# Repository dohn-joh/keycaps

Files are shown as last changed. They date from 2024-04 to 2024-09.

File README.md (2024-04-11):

This repo contains all of the keycaps that I've designed.
I've included parameterized fusion360 files that anyone is free to edit.

# Lever Keycaps
Demo video: https://vimeo.com/897496865

## Switch compatibility
Choc: tested and compatible with choc v1.
MX: currently only tested and working with Outemu Lemon/Lime switches. If your MX switch has a different stem mount, these may not be compatible!
If you use a different switch, you will need to reference the datasheet for your switch, note the pre-travel distance and change the "heel" parameter accordingly.
    
## Notes
- These keycaps will make your switches feel lighter due to leverage. A heavier switch may actually feel better than a lighter one.
- They will alter the actuation distance. You can adjust the parameters to increase or decrease the actuation distance.
- I tried my best to parameterize things, but my sketches are not perfect. Double check the sketches and bodies after changing parameters.

## Hardware and tools required 
Hinge: dressmaker pin with 0.7mm shaft diameter. A box of 350 goes for $4-5 in a brick and mortar store. The exact model used was dritz #22, size 20 (1 ¼") nickel plated steel. it's a little more expensive on amazon. https://www.amazon.com/dp/B003W0TIH6/
You can use other materials for the hinge and change the hole parameters as needed.
Flush cutters: to trim the excess hinge
Optional: tweezer pliers for grabbing and inserting the hinge

## Slicer settings (PLA)
3mf file contains the slicer settings I used in orcaslicer.
The supports are important or the overhangs will sag.

## Assembly
Simply print, remove mouse ears, line up the holes of the base and the paddle, slot the hinge through the holes, and flush cut the excess hinge. Push the assembly onto switch. It should snap into place.

## Troubleshooting
Depending on your printer's tolerances, you may need to adjust the size of the holes and/or the tolerance value. 
Personally, I leverage the walls of my keyboard case to secure the pin in place. A dab of superglue works as well.

# Cylindrical Low Profile
1U keycaps with concavity along the y axis. Designed specifically for thumb usage. Inspired by MCC keycap profile.
Currently only has mx compatibility, but the source file can easily be edited to support choc or other switches.

# Cylindrical Low Profile Choc v2
Thumb: a cross between CS T1 and MCC. Slight concavity for homing thumbs with an asymmetrical shape. Designed for horizontal thumb combo comfort.
Currently choc v2/lofree/mx compatible.

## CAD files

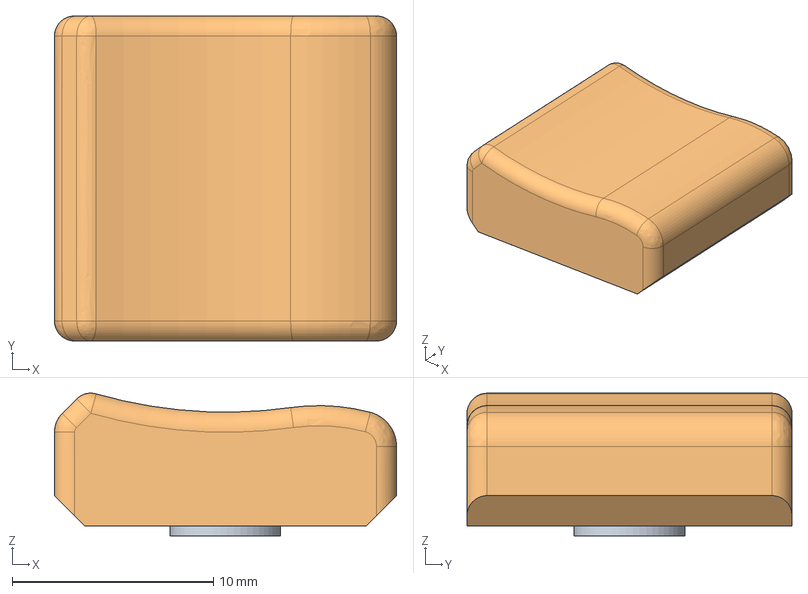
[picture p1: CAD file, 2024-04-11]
cylindrical_lp/Thumb_cylindrical_lp_choc_v2.step
17.0 x 16.1 x 7.10 mm

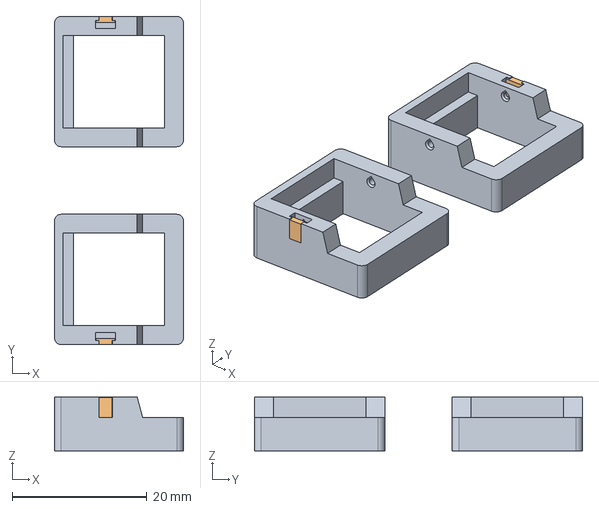
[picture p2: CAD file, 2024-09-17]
lever_keycaps/choc_base_thicc.step
19.1 x 48.6 x 8.00 mm

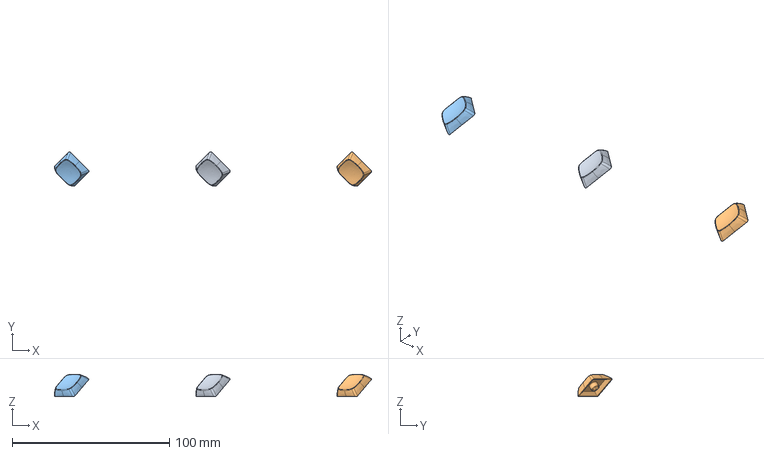
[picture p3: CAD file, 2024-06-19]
mzu/1U.step
201.9 x 21.9 x 14.0 mm

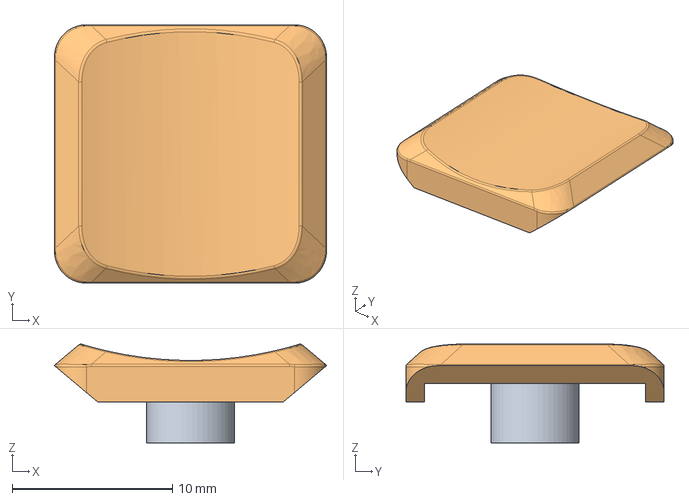
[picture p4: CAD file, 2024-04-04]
cylindrical_lp/mx_cylindrical_lp.step
17.0 x 16.1 x 6.18 mm

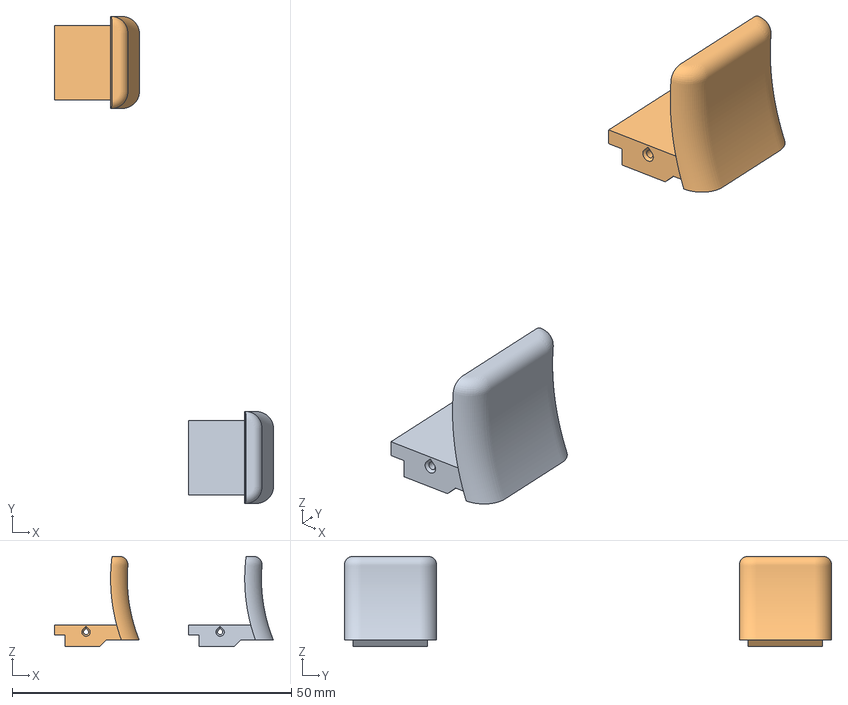
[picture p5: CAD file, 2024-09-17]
lever_keycaps/lever_keycap_orcaslicer_settings.3mf
39.2 x 87.2 x 16.2 mm
choc_paddle_15mm.step x 2

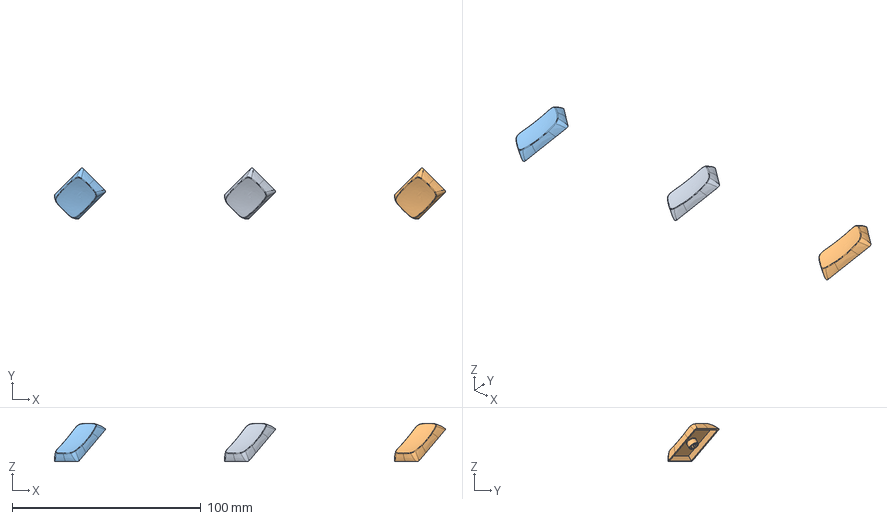
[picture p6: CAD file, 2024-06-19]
mzu/1.5U.step
207.0 x 27.0 x 20.2 mm

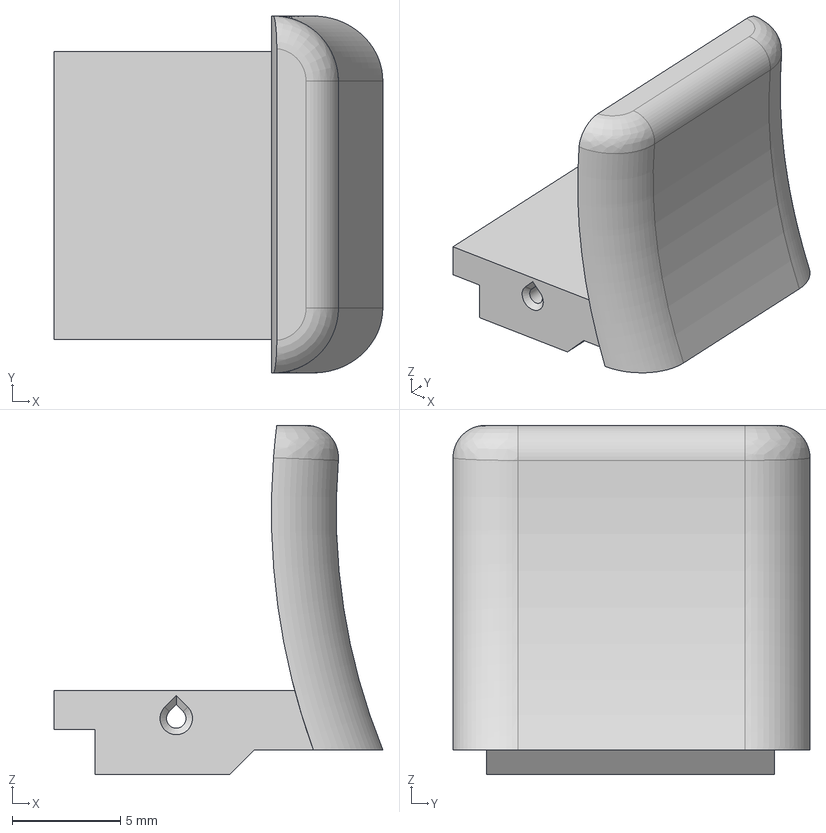
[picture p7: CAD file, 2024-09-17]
lever_keycaps/choc_keycap_15mm.step
15.2 x 16.5 x 16.1 mm

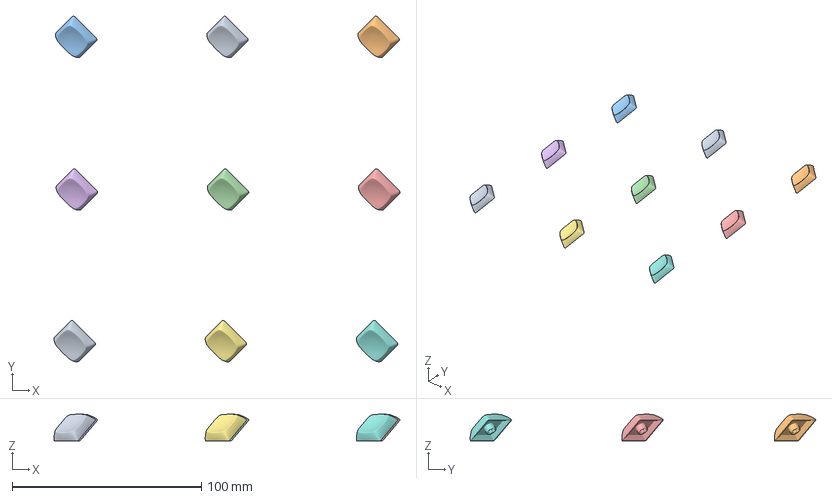
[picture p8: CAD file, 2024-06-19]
mzu/mzu_orcaslicer_settings.3mf
183.1 x 182.9 x 14.0 mm

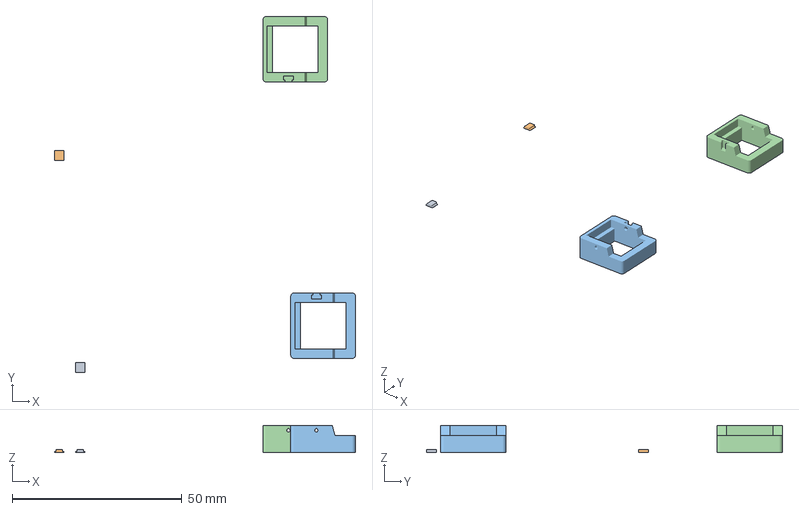
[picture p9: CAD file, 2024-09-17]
lever_keycaps/lever_base_orcaslicer_settings.3mf
88.8 x 105.0 x 8.00 mm
mirror_plug
plug
base
mirror_base

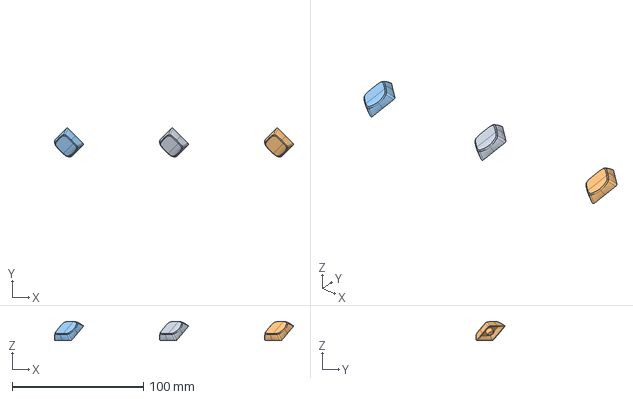
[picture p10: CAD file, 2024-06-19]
mzu/1U_convex.step
182.1 x 22.0 x 14.7 mm

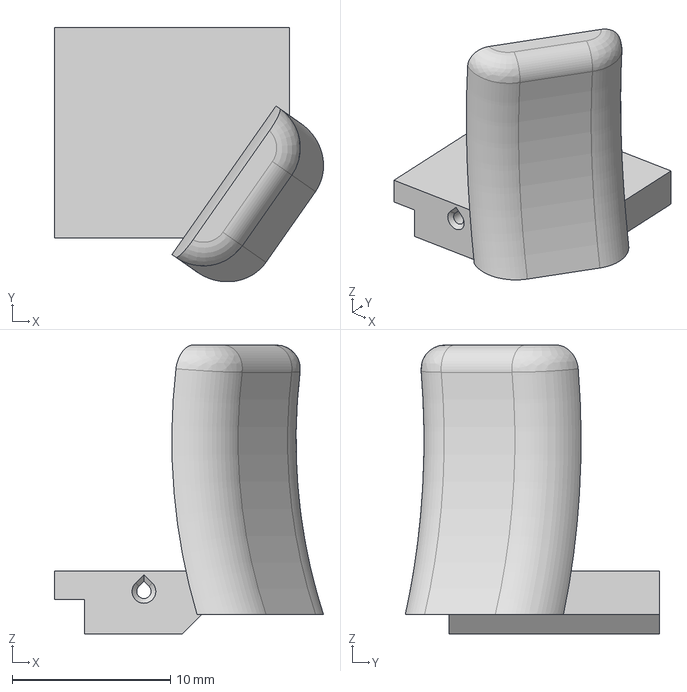
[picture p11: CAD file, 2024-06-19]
lever_keycaps/choc_keycap_angled_17mm.step
17.0 x 16.1 x 18.2 mm

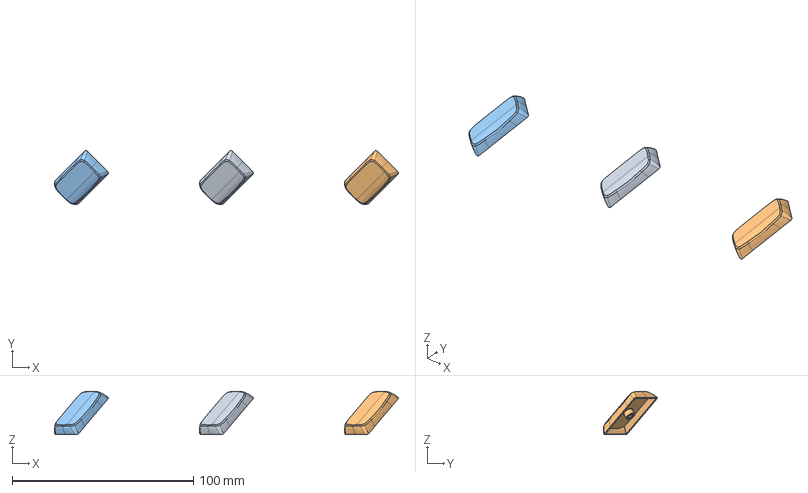
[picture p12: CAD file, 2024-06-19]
mzu/2U_convex.step
189.7 x 29.7 x 23.8 mm

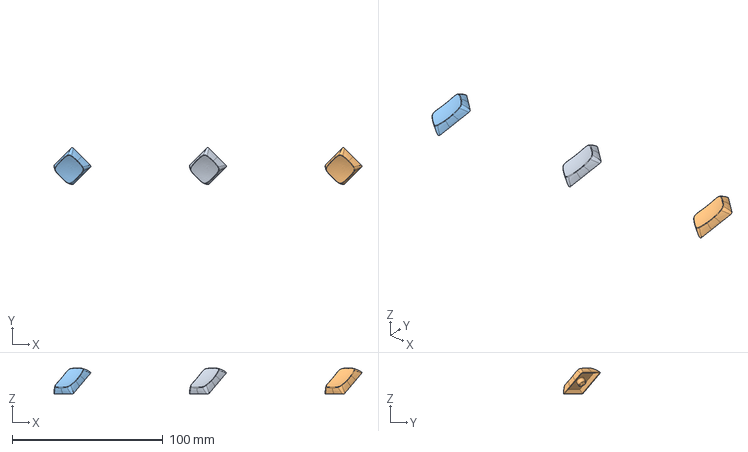
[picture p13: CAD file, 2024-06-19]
mzu/1.25U.step
204.5 x 24.4 x 17.1 mm

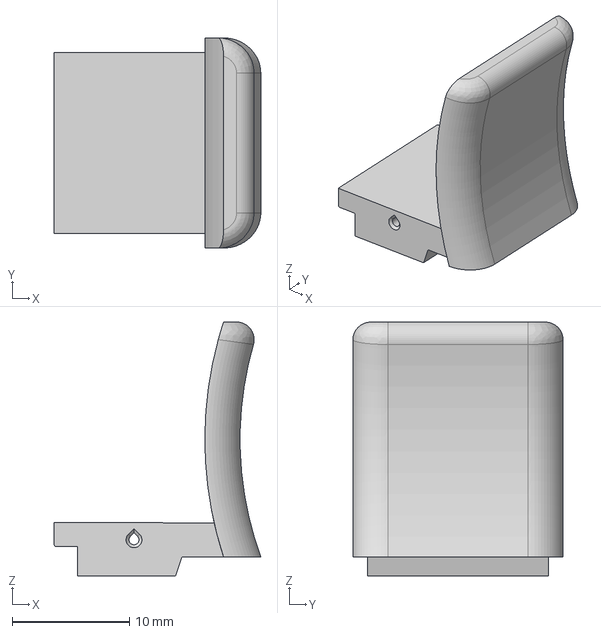
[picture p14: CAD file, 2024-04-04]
lever_keycaps/LIMITED_COMPATIBILITY_mx_keycap.step
17.6 x 17.9 x 21.6 mm

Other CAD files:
lever_keycaps/LIMITED_COMPATIBILITY_mx_base.step
lever_keycaps/OLD_choc_base.step
cylindrical_lp/cylindrical_lp v10.f3z
cylindrical_lp/cylindrical_lp_choc_v2 v7.f3z
lever_keycaps/lever_keycaps v148.f3z
mzu/mzu_concave v40.f3z

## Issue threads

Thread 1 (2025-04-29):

Lever keys not pushing Choc V1s down completely

tsteffek, 2025-04-29:
Hi there, great work.

I instantly loved the idea and printed them. However, while they snap on the switch perfectly, inserting the lever into the base will already push the switch down already, while at the same not pushing far enough to actually trigger the clicking noise (doesn't fit on my keyboard atm, so dry run is all I can do). I'm wondering whether I should just adjust the fusion files, but this seems like a bad default to the degree that I believe I'm doing something wrong. It certainly doesn't look like that in the video.

Any idea?

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
This is the lever sitting on the switch without pushing it down

tsteffek, 2025-05-10:
We solved this issue on discord. To summarize: yes, the lever pressing the switch slightly down is intended to reduce the travel needed to actuate. This was apparently a little too much for my switches and the click happened during assembly and wouldn't recover. I needed to adjust the files a little to get it working, but then it did.

Closed 2025-05-10.

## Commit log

2024-04-11 add slicer settings
    [lever_keycap_orcaslicer.3mf]
2024-05-17 update stl and slicer settings
    [choc_base.step, choc_paddle.step, choc_paddle_18mm.step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]
2024-06-19 update lever_keycap files. add new mzu profile
    [1.25U.step, 1.5U.step, 1U.step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]
2024-09-17 update source file and models
    [LIMITED_COMPATIBILITY_mx_keycap.step, choc_base_thicc.3mf, choc_base_thicc.step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]
